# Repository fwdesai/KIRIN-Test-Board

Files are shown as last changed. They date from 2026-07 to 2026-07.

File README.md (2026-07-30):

Test board for the KIRIN hardware accelerator which was developed by Bo Wun Cheng.

Screenshot 2026-07-26 at 11 04 01 PM

Screenshot 2026-07-30 at 1 47 41 AM

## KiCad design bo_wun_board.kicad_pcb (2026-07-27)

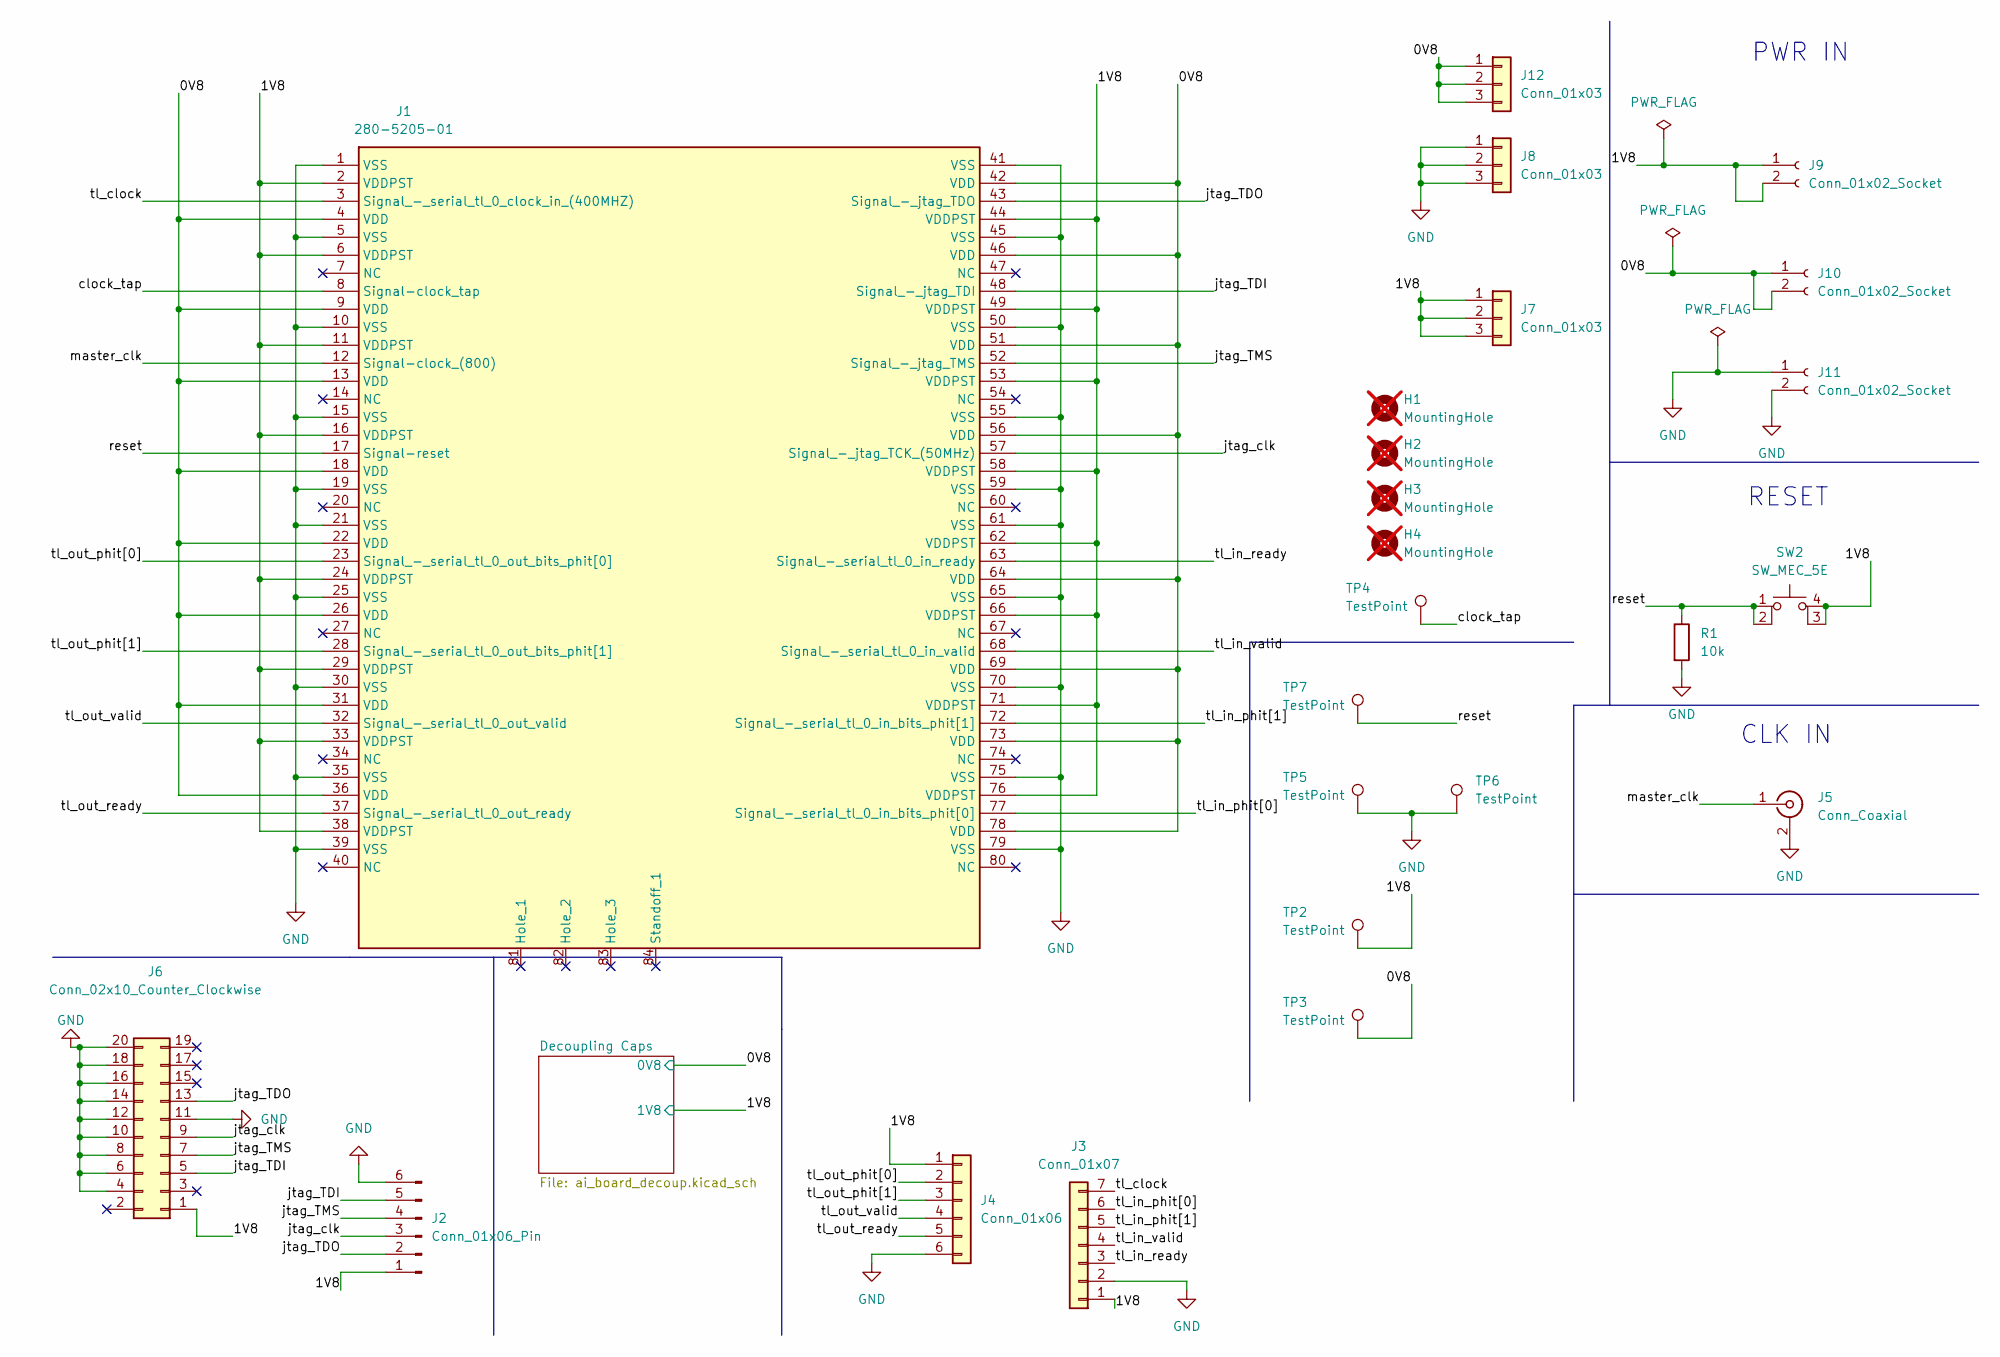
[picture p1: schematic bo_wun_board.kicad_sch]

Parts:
H1, H2, H3, H4: MountingHole; MountingHole_5.3mm_M5; not fitted
J1: 280-5205-01; chip_socket_new; Mouser Part Number 517-280-5205-01
J2: Conn_01x06_Pin; PinHeader_1x06_P2.54mm_Vertical; LCSC Part # C5156615
J3: Conn_01x07; PinHeader_1x07_P2.54mm_Vertical; LCSC Part # C5360900
J4: Conn_01x06; PinHeader_1x06_P2.54mm_Vertical; LCSC Part # C5156615
J5: Conn_Coaxial; SMA_Amphenol_132134-16_Vertical; LCSC Part # C2987686
J6: Conn_02x10_Counter_Clockwise; smd_jtag_connector
J7, J8, J12: Conn_01x03; PinHeader_1x03_P2.54mm_Vertical; LCSC Part # C5360899
J9: Conn_01x02_Socket; CONN_24.243_MTC; LCSC Part # C7437323
J10: Conn_01x02_Socket; CONN_24.243_MTC; LCSC Part # C7437321
J11: Conn_01x02_Socket; CONN_24.243_MTC; LCSC Part # C7437322
R1: 10k; R_0402_1005Metric; LCSC Part # C25744
SW2: SW_MEC_5E; teco_push_button; LCSC Part # C428628
TP2: TestPoint; TestPoint_Keystone_5010-5014_Multipurpose; LCSC Part # C238128
TP3: TestPoint; TestPoint_Keystone_5010-5014_Multipurpose; LCSC Part # C2906765
TP4: TestPoint; TestPoint_Keystone_5010-5014_Multipurpose; LCSC Part # C2906767
TP5, TP6: TestPoint; TestPoint_Keystone_5010-5014_Multipurpose; LCSC Part # C238127
TP7: TestPoint; TestPoint_Keystone_5010-5014_Multipurpose; LCSC Part # C2906766

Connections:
/0V8: J1.4 (VDD), J1.9 (VDD), J1.13 (VDD), J1.18 (VDD), J1.22 (VDD), J1.26 (VDD), J1.31 (VDD), J1.36 (VDD), J1.42 (VDD), J1.46 (VDD), J1.51 (VDD), J1.56 (VDD), J1.64 (VDD), J1.69 (VDD), J1.73 (VDD), J1.78 (VDD), J10.1, J10.2, J12.1, J12.2, J12.3, TP3.1 (1_1); also elsewhere on the board
/1V8: J1.2 (VDDPST), J1.6 (VDDPST), J1.11 (VDDPST), J1.16 (VDDPST), J1.24 (VDDPST), J1.29 (VDDPST), J1.33 (VDDPST), J1.38 (VDDPST), J1.44 (VDDPST), J1.49 (VDDPST), J1.53 (VDDPST), J1.58 (VDDPST), J1.62 (VDDPST), J1.66 (VDDPST), J1.71 (VDDPST), J1.76 (VDDPST), J2.1, J3.1, J4.1, J6.1, J7.1, J7.2, J7.3, J9.1, J9.2, SW2.3 (K), SW2.4 (A), TP2.1 (1_1); also elsewhere on the board
/clock_tap: J1.8 (Signal-clock_tap), TP4.1 (1_1)
/jtag_TDI: J1.48 (Signal_-_jtag_TDI), J2.5, J6.5 (Pin_3)
/jtag_TDO: J1.43 (Signal_-_jtag_TDO), J2.2, J6.13 (Pin_7)
/jtag_TMS: J1.52 (Signal_-_jtag_TMS), J2.4, J6.7 (Pin_4)
/jtag_clk: J1.57 (Signal_-_jtag_TCK_(50MHz)), J2.3, J6.9 (Pin_5)
/master_clk: J1.12 (Signal-clock_(800)), J5.1 (In)
/reset: J1.17 (Signal-reset), R1.1, SW2.1, SW2.2, TP7.1 (1_1)
/tl_clock: J1.3 (Signal_-_serial_tl_0_clock_in_(400MHZ)), J3.7
/tl_in_phit[0]: J1.77 (Signal_-_serial_tl_0_in_bits_phit[0]), J3.6
/tl_in_phit[1]: J1.72 (Signal_-_serial_tl_0_in_bits_phit[1]), J3.5
/tl_in_ready: J1.63 (Signal_-_serial_tl_0_in_ready), J3.3
/tl_in_valid: J1.68 (Signal_-_serial_tl_0_in_valid), J3.4
/tl_out_phit[0]: J1.23 (Signal_-_serial_tl_0_out_bits_phit[0]), J4.2
/tl_out_phit[1]: J1.28 (Signal_-_serial_tl_0_out_bits_phit[1]), J4.3
/tl_out_ready: J1.37 (Signal_-_serial_tl_0_out_ready), J4.5
/tl_out_valid: J1.32 (Signal_-_serial_tl_0_out_valid), J4.4
GND: J1.1 (VSS), J1.5 (VSS), J1.10 (VSS), J1.15 (VSS), J1.19 (VSS), J1.21 (VSS), J1.25 (VSS), J1.30 (VSS), J1.35 (VSS), J1.39 (VSS), J1.41 (VSS), J1.45 (VSS), J1.50 (VSS), J1.55 (VSS), J1.59 (VSS), J1.61 (VSS), J1.65 (VSS), J1.70 (VSS), J1.75 (VSS), J1.79 (VSS), J2.6, J3.2, J4.6, J5.2 (Ext), J6.4 (Pin_19), J6.6 (Pin_18), J6.8 (Pin_17), J6.10 (Pin_16), J6.11 (Pin_6), J6.12 (Pin_15), J6.14, J6.16 (Pin_13), J6.18 (Pin_12), J6.20 (Pin_11), J8.1, J8.2, J8.3, J11.1, J11.2, R1.2, TP5.1 (1_1), TP6.1 (1_1); also elsewhere on the board

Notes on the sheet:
PWR IN
CLK IN
RESET

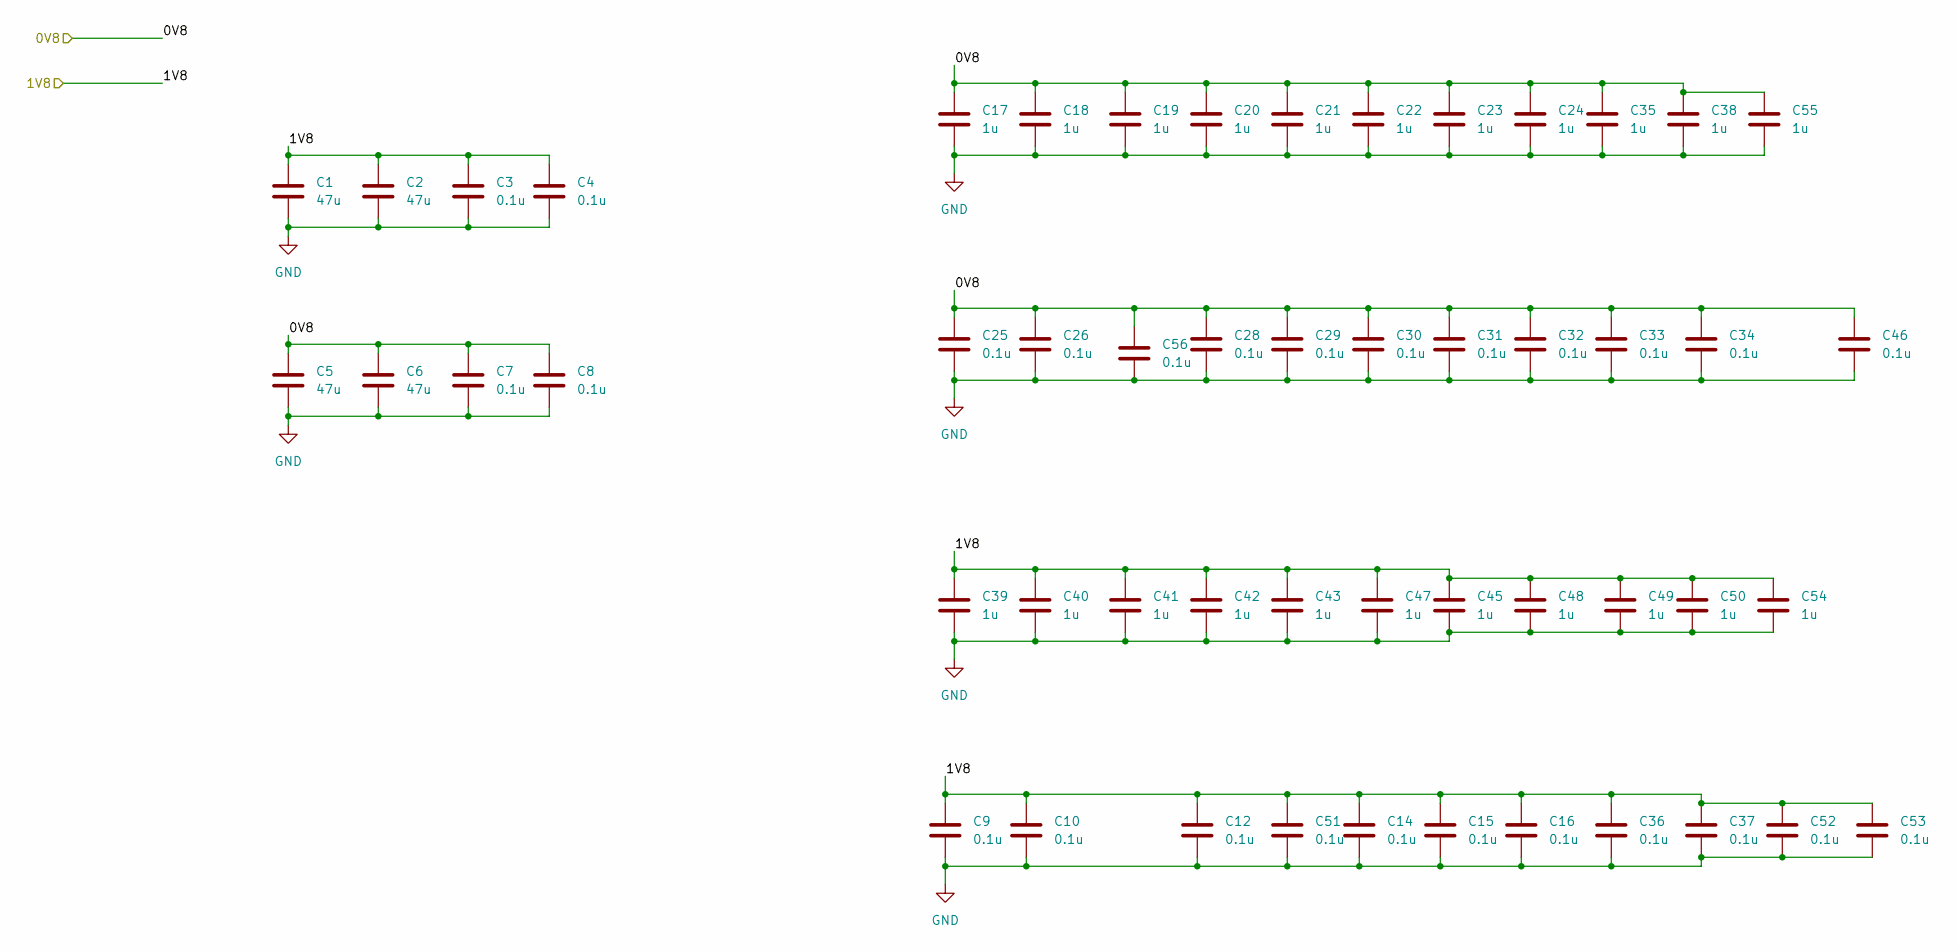
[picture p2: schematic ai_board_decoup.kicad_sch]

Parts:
C1, C2, C5, C6: 47u; C_0805_2012Metric; LCSC C16780
C3, C4, C7, C8, C9, C10, C12, C14, C15, C16, C25, C26, C28, C29, C30, C31, C32, C33, C34, C36, C37, C46, C51, C52, C53, C56: 0.1u; C_0402_1005Metric; LCSC C1525
C17, C18, C19, C20, C21, C22, C23, C24, C35, C38, C39, C40, C41, C42, C43, C45, C47, C48, C49, C50, C54, C55: 1u; C_0805_2012Metric; LCSC C28323

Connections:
/0V8: C5.1, C6.1, C7.1, C8.1, C17.1, C18.1, C19.1, C20.1, C21.1, C22.1, C23.1, C24.1, C25.1, C26.1, C28.1, C29.1, C30.1, C31.1, C32.1, C33.1, C34.1, C35.1, C38.1, C46.1, C55.1, C56.1; also elsewhere on the board
/1V8: C1.1, C2.1, C3.1, C4.1, C9.1, C10.1, C12.1, C14.1, C15.1, C16.1, C36.1, C37.1, C39.1, C40.1, C41.1, C42.1, C43.1, C45.1, C47.1, C48.1, C49.1, C50.1, C51.1, C52.1, C53.1, C54.1; also elsewhere on the board
GND: C1.2, C2.2, C3.2, C4.2, C5.2, C6.2, C7.2, C8.2, C9.2, C10.2, C12.2, C14.2, C15.2, C16.2, C17.2, C18.2, C19.2, C20.2, C21.2, C22.2, C23.2, C24.2, C25.2, C26.2, C28.2, C29.2, C30.2, C31.2, C32.2, C33.2, C34.2, C35.2, C36.2, C37.2, C38.2, C39.2, C40.2, C41.2, C42.2, C43.2, C45.2, C46.2, C47.2, C48.2, C49.2, C50.2, C51.2, C52.2, C53.2, C54.2, C55.2, C56.2; also elsewhere on the board

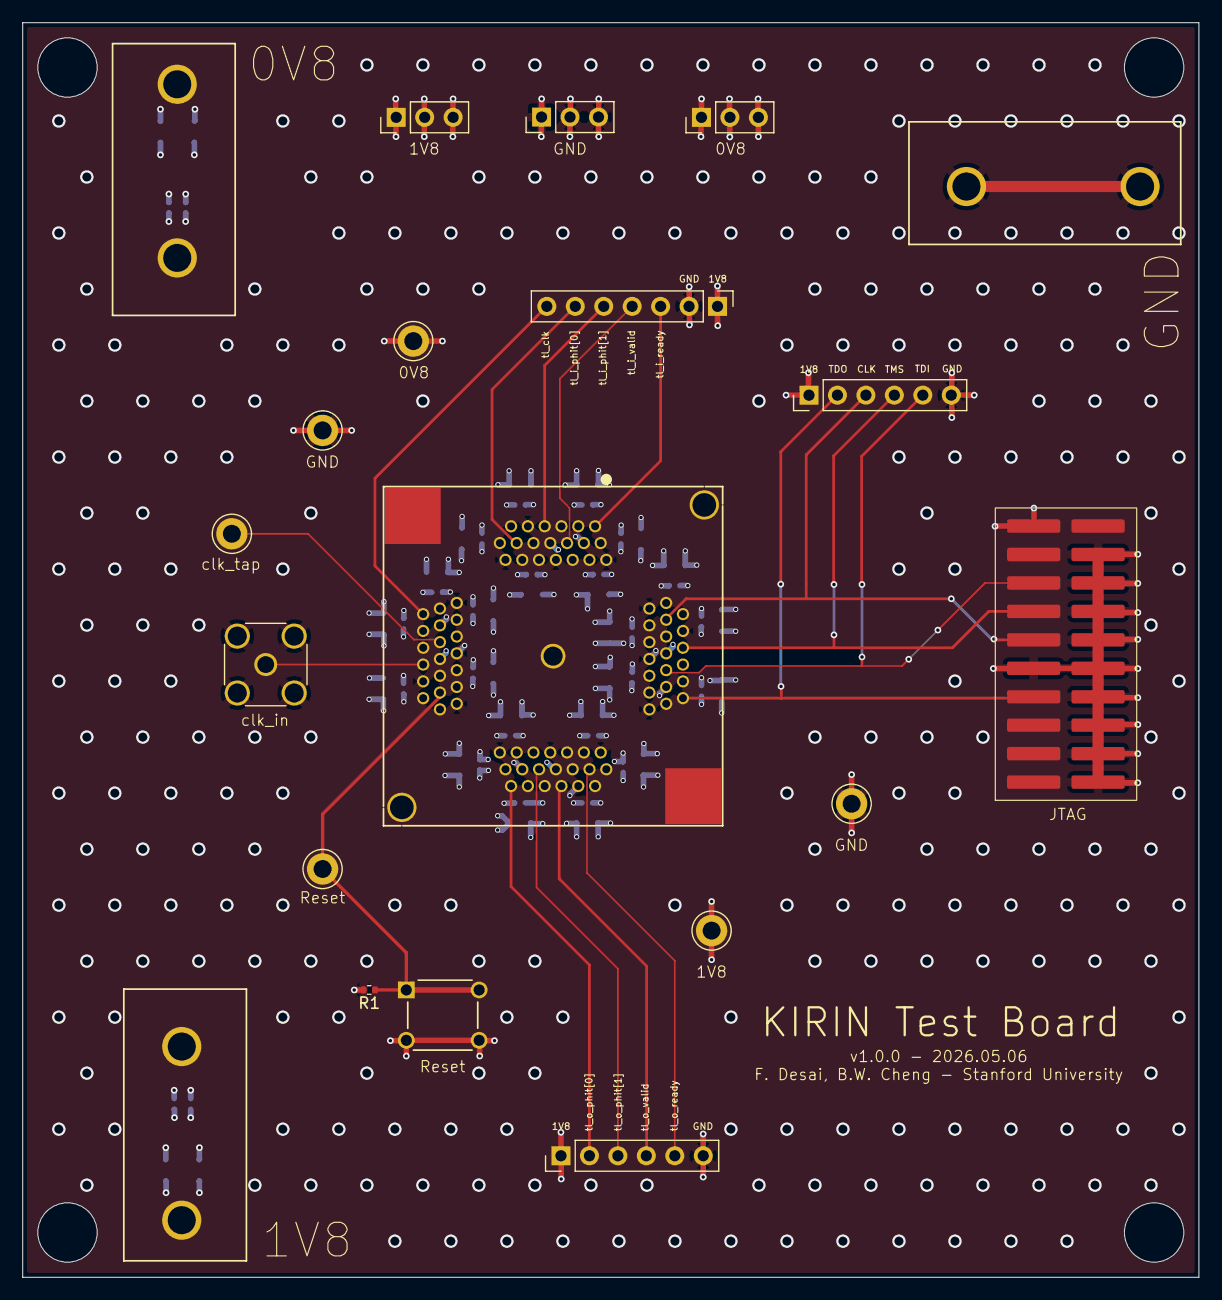
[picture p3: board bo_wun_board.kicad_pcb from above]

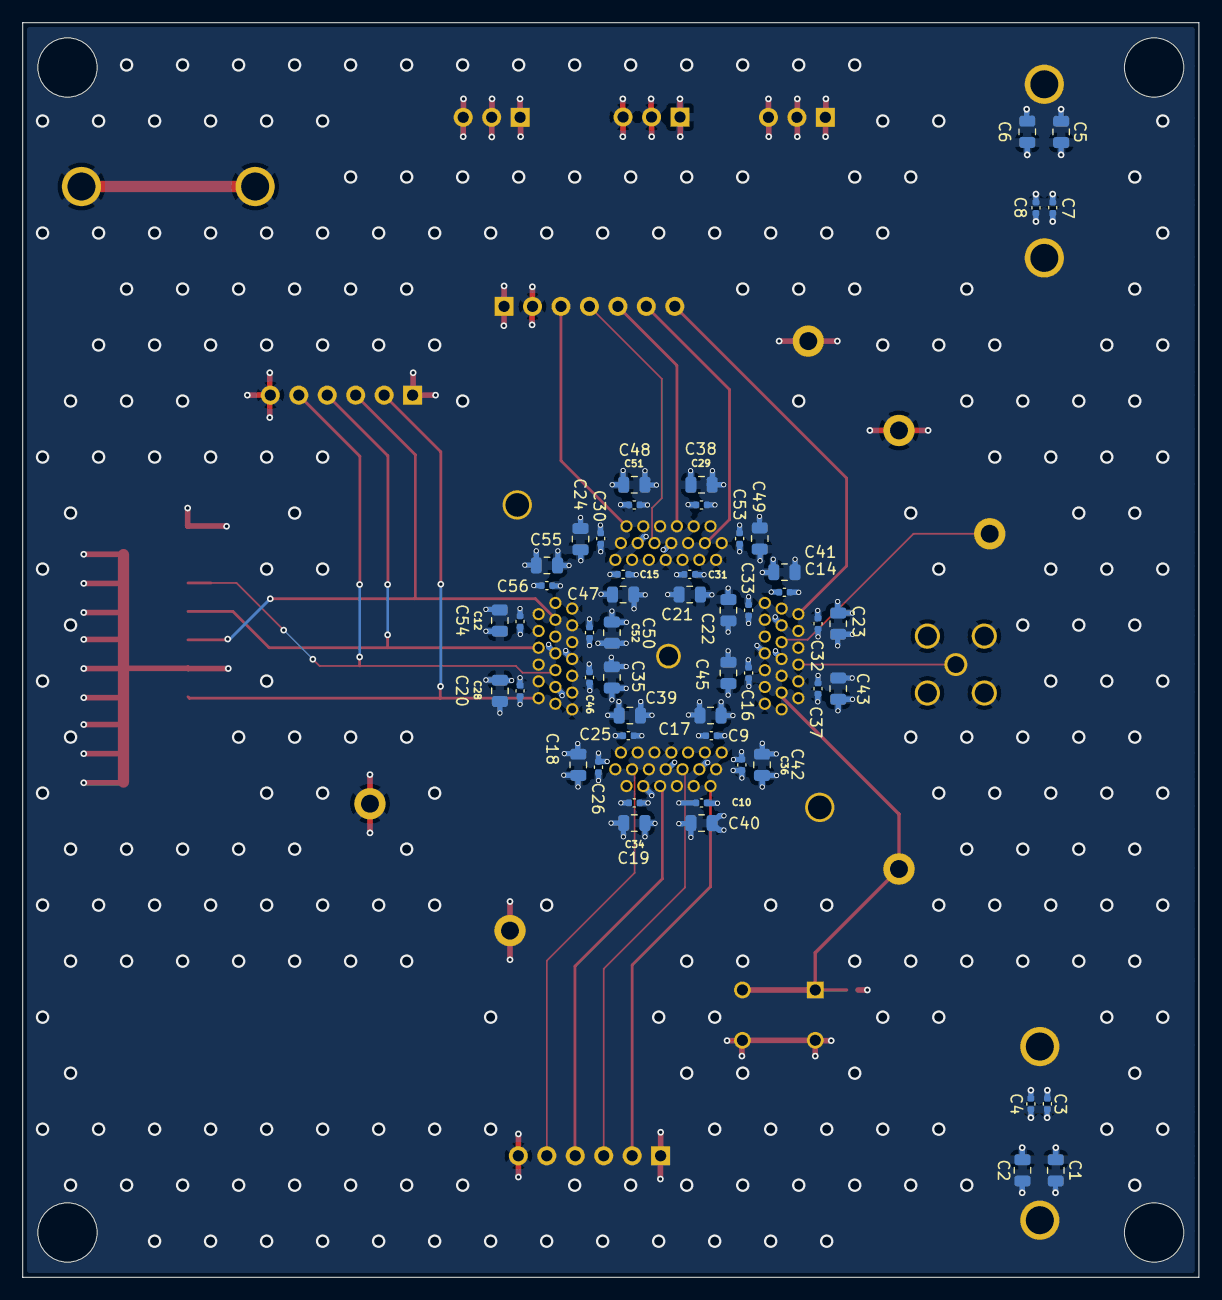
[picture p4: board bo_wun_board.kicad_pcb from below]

Board: 6 copper layers, 105.0 x 112.0 mm, 76 parts (52 on the bottom side), 19 nets.
